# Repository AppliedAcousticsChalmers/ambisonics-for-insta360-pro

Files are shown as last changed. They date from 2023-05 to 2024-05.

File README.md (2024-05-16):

# Experimental 4th-Order Ambisonic Microphone Array for the Insta360 Pro Camera

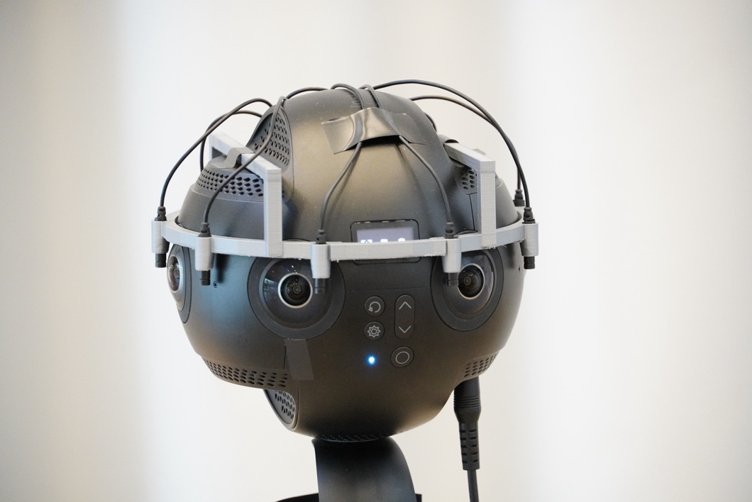
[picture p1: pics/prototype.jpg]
prototype


This repository comprises resources related to the 4th ambisonic order microphone array prototype that we created for the Insta360 Pro camera. Here is a demonstration video of it: https://youtu.be/5jAu47l2WaY. Other designs for ambisonic microphone arrays are found in [this repository](https://github.com/AppliedAcousticsChalmers/ambisonic-microphone-arrays).

The folder `3d_model` comprises resources related to the design of the microphone mount. The folder `signal_processing` comprises resources related to the processing of the signals that the microphones of the array capture. You will also find the raw signals there from which the above demonstration video was created.  The scripts have been created for MATLAB. Minor tweaks are required for making some them work on Octave. We'll provide that shortly. See [this](https://github.com/AppliedAcousticsChalmers/ambisonic-encoding/commit/76088d25df88498b9505526ae59e62d48b10267b) commit to get an idea of what kind of edits are required. The MagLS rendering has not been tested with Octave. But we'll do that shortly, too.

When using these resources, please cite the following paper in which we presented the prototype for the very first time:

    J. Ahrens and K. Jaruszewska, "Case Study of Equipping a High-Fidelity 360 Camera 
    with a 4th-Order Equatorial Ambisonic Microphone Array," 154th Convention of the AES, 
    Espoo, Finland (2023). 
    
Find a pdf of the paper [here](https://research.chalmers.se/publication/535721/file/535721_Fulltext.pdf).

## License
The content of this repository is licensed under the terms of the MIT license. Please consult the file [LICENSE](LICENSE) for more information about this license.

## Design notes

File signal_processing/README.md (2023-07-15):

# Signal Processing

(Make sure to invoke `git submodule update --init --recursive` to get all submodules of this repository.)

The signal processing assumes that the camera housing is a sphere. The camera housing does indeed have a perfectly circular equator, but it has these cutouts at the top and at the bottom, and it is a little squashed. We demonstrated in the following paper that the acoustic effect of these deviations is negligible:

    J. Ahrens and K. Jaruszewska, "Case Study of Equipping a High-Fidelity 360 Camera with a 4th-Order Equatorial Ambisonic Microphone Array," 154th Convention of the AES, Espoo, Finland (2023). [[pdf]](https://research.chalmers.se/publication/535721/file/535721_Fulltext.pdf)

The signal processing that we apply to the raw microphone signals is therefore in principle identical to what is described in

    J. Ahrens, "Ambisonic Encoding of Signals From Equatorial Microphone Arrays," 
    Technical note v. 1, Chalmers University of Technology, Aug. 2022.

[(pdf)](https://arxiv.org/pdf/2211.00584.pdf) and to what is implemented in https://github.com/AppliedAcousticsChalmers/ambisonic-encoding. The difference in the present case is that we additionally perform an equalization of the processing pipeline with respect to the spectral balance of the binaural output signals. Actually, we provide you with two alternative equalizations here.

## Diffuse-Field Equalisation of the Array Plus MagLS Rendering

The motivation behind this is the following: MagLS rendering as presented in 

    C. Schörkhuber, M. Zaunschirm, R. Höldrich, “Binaural rendering of Ambisonic signals 
    via magnitude least squares,” in Proc. DAGA, vol. 44, 2018, pp. 339–342.
    
and consists essentially in replacing the raw order-limited HRTFs that are used for the binaural rendering with a variant of these HRTFs that have a compensation of the effects of the order-limitation built-in so that the attenuation at high frequencies (say, above 3 kHz in the present case) that is inherent to order-limited HRTFs is compensated for as best as possible. This means that we can assume that the rendering part of the pipeline does not affect the spectral balance of the binaural output signals.

How about the array itself? A perfect equatorial microphone array (EMA) will produce spherical harmonic (SH) coefficients that exhibit a perfectly flat magnitude spectrum if the incidence sound field is a horizontally propagating plane wave in free-field conditions. The SH coefficients that a real-world EMA produces are corrupted by spatial aliasing, which usually causes excess energy above the spatial aliasing frequency (which is approx. 3 kHz for the present array). A real-world array will also produce too low energy at low frequencies for orders higher than 0 because of the gain limitation of the radial filters. But we can disregard that because it does not affect the spectral balance of the binaural output signals. 

We therefore need to take into account only the spatial aliasing. To do that, we simulated horizontal plane wave incidence for 60 different azimuths onto our EMA and computed the average deviation of the magnitude spectrum of the resulting SH coefficients from flat at frequencies above the aliasing frequency. Based on that, we created a minimum-phase filter that compensates for the average deviation and simply apply that filter to all signal channels (you can do it before or after the SH decomposition). Here is what the filter's transfer function looks like: 

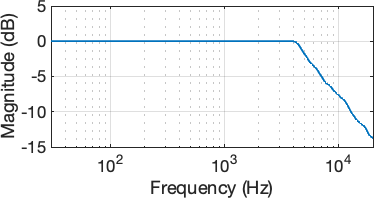
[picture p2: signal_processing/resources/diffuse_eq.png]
diffuse_eq


The filter is stored in the file `resources/diffuse_eq_Insta360.mat`.

Done! This way, we equalised the array, and the rendering is equalized via MagLS. Check the script `render_recording.m` for the complete pipeline. You'll need to download the employed HRIRs from [here](https://zenodo.org/record/3928297/files/HRIR_L2702.sofa?download=1) and store them in the subfolder `eMagLS/resources` (The MATLAB script is going to do that automatically for you.) as well as the SOFA MATLAB API from [here](https://sourceforge.net/projects/sofacoustics/) for being able to compute the binaural output yourself. The ambisonic encoding works either way.

Note that this script also stores the free-field equalised ambisonic signals from the array in N3D format, which you can render yourself in [Reaper](https://www.reaper.fm/), for example, with the IEM Binaural Renderer (which performs MagLS rendering, too, by the way). The repository comprises the Reaper project `binaural_rendering.rpp` that reads the ambisonic signals and renders them binaurally in realtime. This allows for using head tracking if you happen to have a tracker available. The Reaper project requires the [IEM Plugin Suite](https://plugins.iem.at/) to be installed.

## Manual Global Equalization

MagLS provides most significant improvement at low orders around, say, 2. The present array is 4th order where the benefits tend to become less pronounced. We therefore tested also a simple equalization procedure (this is actually what we used in the video): 

We do the plain SH decomposition and binaural rendering as described in the paper (Ahrens, 2022) referenced above and compare the spectral balance of the binaural output to the ground truth. When rendering a plane wave, the ground truth is simply the HRTF for the incidence direction of that plane wave. It turned out that the deviation of the magnitude spectrum of the binaural output is only very mildly dependent on the incidence direction of the sound so that we chose to use a single minimum-phase filter to compensate for it globally. It is a simple shelving filter that boosts the signal by approx. 3 dB above 3 kHz:

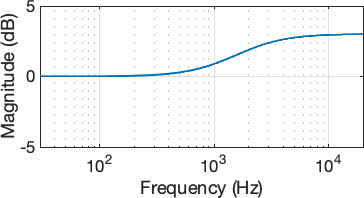
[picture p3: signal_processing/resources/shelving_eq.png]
shelving_eq


The script `render_recording.m` allows you to set flags such that this equalization is performed instead of diffuseEQ+MagLS.

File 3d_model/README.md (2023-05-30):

# The Microphone Mount

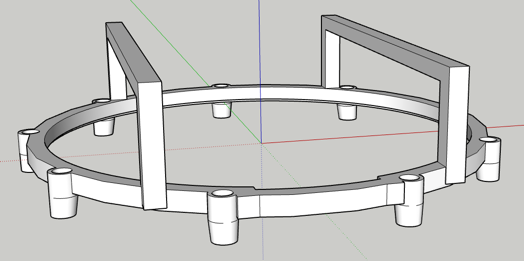
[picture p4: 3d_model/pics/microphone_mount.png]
microphone_mount


This folder comprises the 3D model of the microphone mount, which was created in SketchUp and 3D printed. The mount is designed for 9 pcs. of Røde Lavalier GO omnidirectional lapel microphones. To fit the microphones into the mount, wrap the microphone bodies 1.5 times with eletrical tape such that the edge of the tape coincides with the step of the radius of the cylindrical microphone body that occurs at the pull relief. See the following picture:

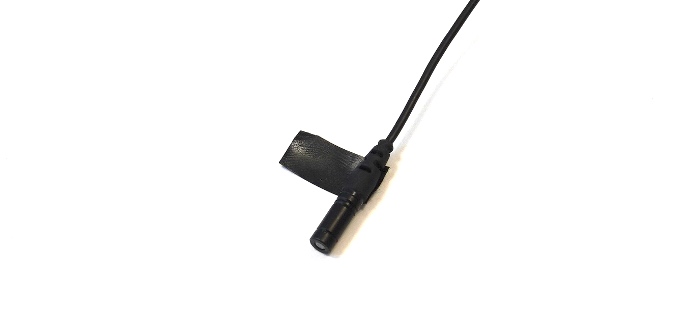
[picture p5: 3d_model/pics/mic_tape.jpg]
mic_tape


This way, the microphones sit firmly in the correct position and do not require any further securing. 

We used the same tape for taping the microphone wires against the camera body. We also recommend taping the mount onto the camera because it may otherwise move when the camera is being moved. Refer also to the title photo of this repository to see this. 

As our experience with 3D modelling and 3D printing are limited, we see potential for improvement of the design:

* Currently, there is a gap with a width of approx. 2 mm between the microphone diaphragms and the camera surface. It is not critical, but it may be possible to either angle the microphones such that their tips end up close to the camera surface, or, it may be possible to keep them vertical but move them closer.
* The microphones all sit on a ring that sits of the camera housing. The ring is partly visible to the cameras so that it occludes the field of view in upward direction. It may be possible to avoid this by placing the ring higher up and add arms to it on which the cameras sit.
* It may be useful add cables holders to the design so that the cables do not need to be taped. 
* It may be possible to come up with a design that allows for strapping the mount onto the camera so that no taping is required at all. 

Here are a couple more details that'll help you improving the design if aim for that:

* Radius of the circle along which the camera housing and the microphone mount have contact: 70.5 mm
* Radius of the circle through the centers of the microphones: 76 mm
* The underside of the horizontal bars across the camera housing is 29 mm above the circle along which the camera housing and the microphone mount have contact.
* All beam-like parts have a 6 mm x 6 mm cross-section.
* Here is a vertical cross-section through the microphone holders:

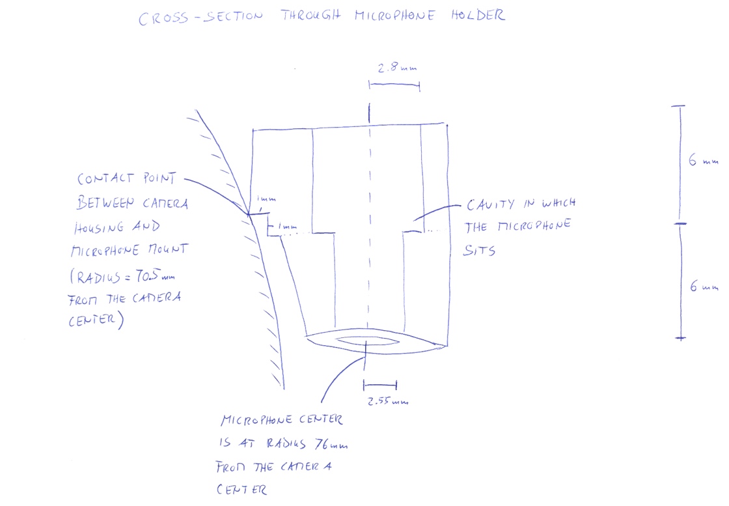
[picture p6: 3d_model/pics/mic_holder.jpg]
mic_holder


If you happen to be able to produce an improved design, then please let us know at jens.ahrens@chalmers.se!

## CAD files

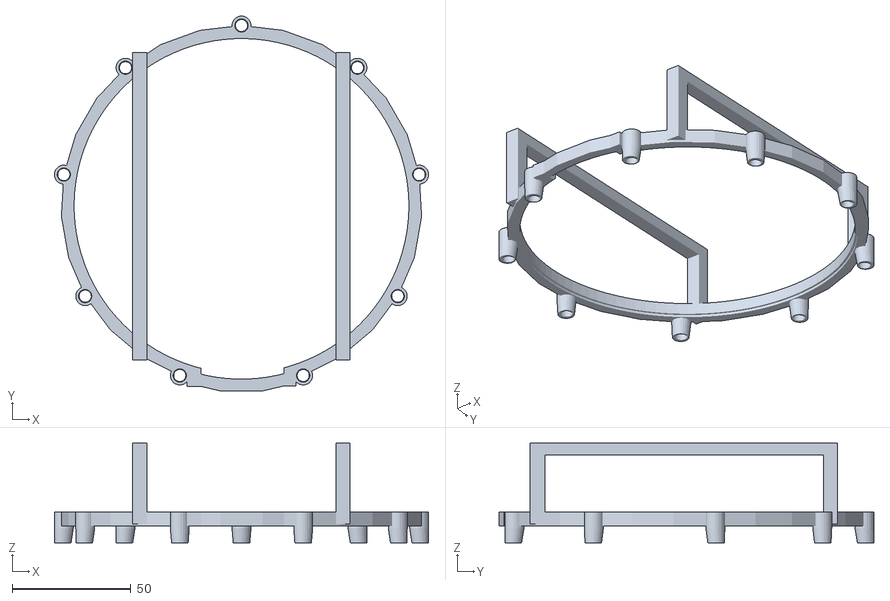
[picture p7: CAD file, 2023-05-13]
3d_model/microphone_mount.stl
157.7 x 158.0 x 42.0

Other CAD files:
3d_model/microphone_mount.skp

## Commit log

2023-05-13 Publish 1st version
    [microphone_mount.skp, microphone_mount.stl]
2023-05-30 Add details on the mic mount
